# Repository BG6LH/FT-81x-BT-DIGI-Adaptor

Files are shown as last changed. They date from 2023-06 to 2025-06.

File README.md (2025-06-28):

views
views per week
clones
clones per week

Since 2025/06/11 



---
English | [简体中文](./README.zh-CN.md)

# A PCB Design of Bluetooth DIGI Adaptor for Yaesu FT-817/818 Series Transceivers

> **NOTE: This Design is still a Work in Progress. Schematic, PCB, and other stuff might change!**

## Table of Contents
- [Update](#update)
- [Important](#important)
- [Background](#background)
- [Design](#design)
- [Code Repositories](#code-repositories)
- [Configuration of JDY-67](#configuration-of-JDY-67)
- [3D Printed Protect Cover](#3d-printed-protect-cover)
- [Related Efforts](#related-efforts)
- [Contributing](#contributing)
- [Maintainers](#maintainers)
- [License](#license)

## Update

### Updated in 20240120

**Important:** Fixed the 20230609 version‘s power supply part's resistor value.

Right Choice should be this:
* R10 = 100KΩ
* R11 = 100KΩ
* R12 = 1KΩ
* R6 = 10Ω

The LM1117-3.3V is also a good choice.
All about that can work well at once!

The PCB design is as same as 20230609, so the old Gerber files are still work.

A 3D printed Cover has published:

[https://www.thingiverse.com/thing:6116435](https://www.thingiverse.com/thing:6116435)

### Updated in 20230609 

**Important:** The 20230608 version‘s symbols and footprints of Q1, Q2 are wrong. Please use updated in 20230609.

1. Update LDO LM1117-3.3V to 5V, to provide a constant power for the Bluetooth module;
2. Removed the Zener, and updated R6 to 150Ω, which is close to the ideal value;
3. Added power off circuit.
4. Replace VR with fixed resistor and optimize the circuit.
5. Updated some symbols and footprints.

### Updated in 20230527

The version 20230522‘s MD6 and MD8 sockets footprints were forgot to be grounded, if you has printed the PCB, you can scrape the green oil next to the shell's big pin, and then solder them together. It will as good as this version 20230527.

20230527's update includes:
1. Modified the symbols and footprints design of MD-6 and MD8 sockets, added pin 9, and grounded. Ensure that will not lost ground when updating from schematic.
2. The power divider resistor R6 is updated to 270Ω, which is close to the ideal value;
3. Added project's kicad symbols and footprints library sharing.

### Updated in 20230522
1. Add 6.2V zener for pre-conditioning before LM1117-3.3
2. Add attenuation network for Line->Mic
3. Add EMI inductor on TXD/RXD pins.
4. Removed TXD's LED.

## Important
1. The FT-817/818's ACC jack always has a constant voltage of 13.8V, even you switched off the rig. We should ***BE VERY CAREFUL*** to avoid short-circuit the PCB and ACC jack accidentally.
2. Meanwhile, aftering installing this adaptor, it will ***ALWAYS*** consume FT-817/818's battery energy. So, A battery with a power switch is recommended. For example, The WindCamp's FT-817/818 lithium battery.
3. If you would purchase a JDY-67 Bluetooth moudle, make sure the firmware version is ***Above 1.3***.

## Background
My friend BG6JJI designed a Bluetooth DIGI adaptor working for many old style TRXs with a Bluetooth, DIGI and CAT ability. He was using a Bluetooth module named JDY-67. I am not sure which manufacturer made the JDY-67. But it's really inexpensive and really works for Bluetooth Audio, and SPP in same time.

So, I pick up an old PCB design for my FT-818. It was design for FT8 cable connecting at very beginning. However, with JDY-67, It should works for Bluetooh/DIGI/CAT. I'd measured the DATA and ACC jacks on FT-818's rear panel, And refering to the FT-817ND's Service Manual, I think the Yaesu's PCB maybe design in a 0.635mm/0.025inch grid. Under this assumption, I'd drawn a PCB that could cover most of the FT-817 rear panel, and perfectly matched all the screw holes, jacks....precisely!!! It looks like a underwear(under-bottom-hardware), right?

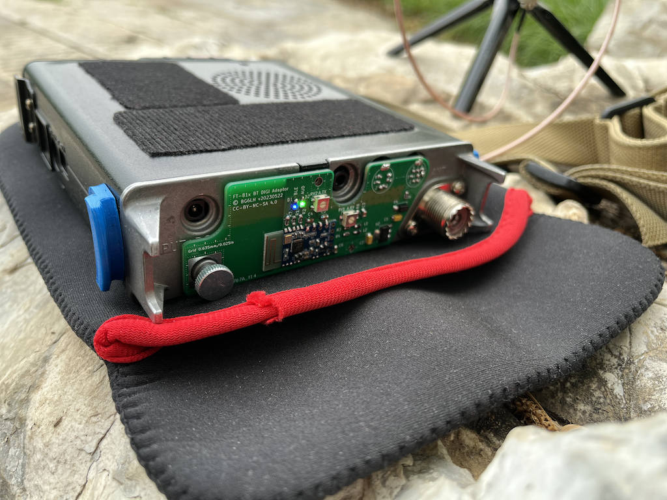
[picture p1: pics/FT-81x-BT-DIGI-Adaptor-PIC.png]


Although FT-817/818 has been discontinued, I still love this twenty years selling product. Now, I would like to share this PCB desgin to all HAM communities, If you wanna make your design, you can make any modify from it.

## Design
This PCB was design by KiCad 7.0
In the Layer User.Drawings and User.Comments, there are some information of measurement.
In the Layer User.1~4, there are approximate FT-817/818's panel sketch for comparison.

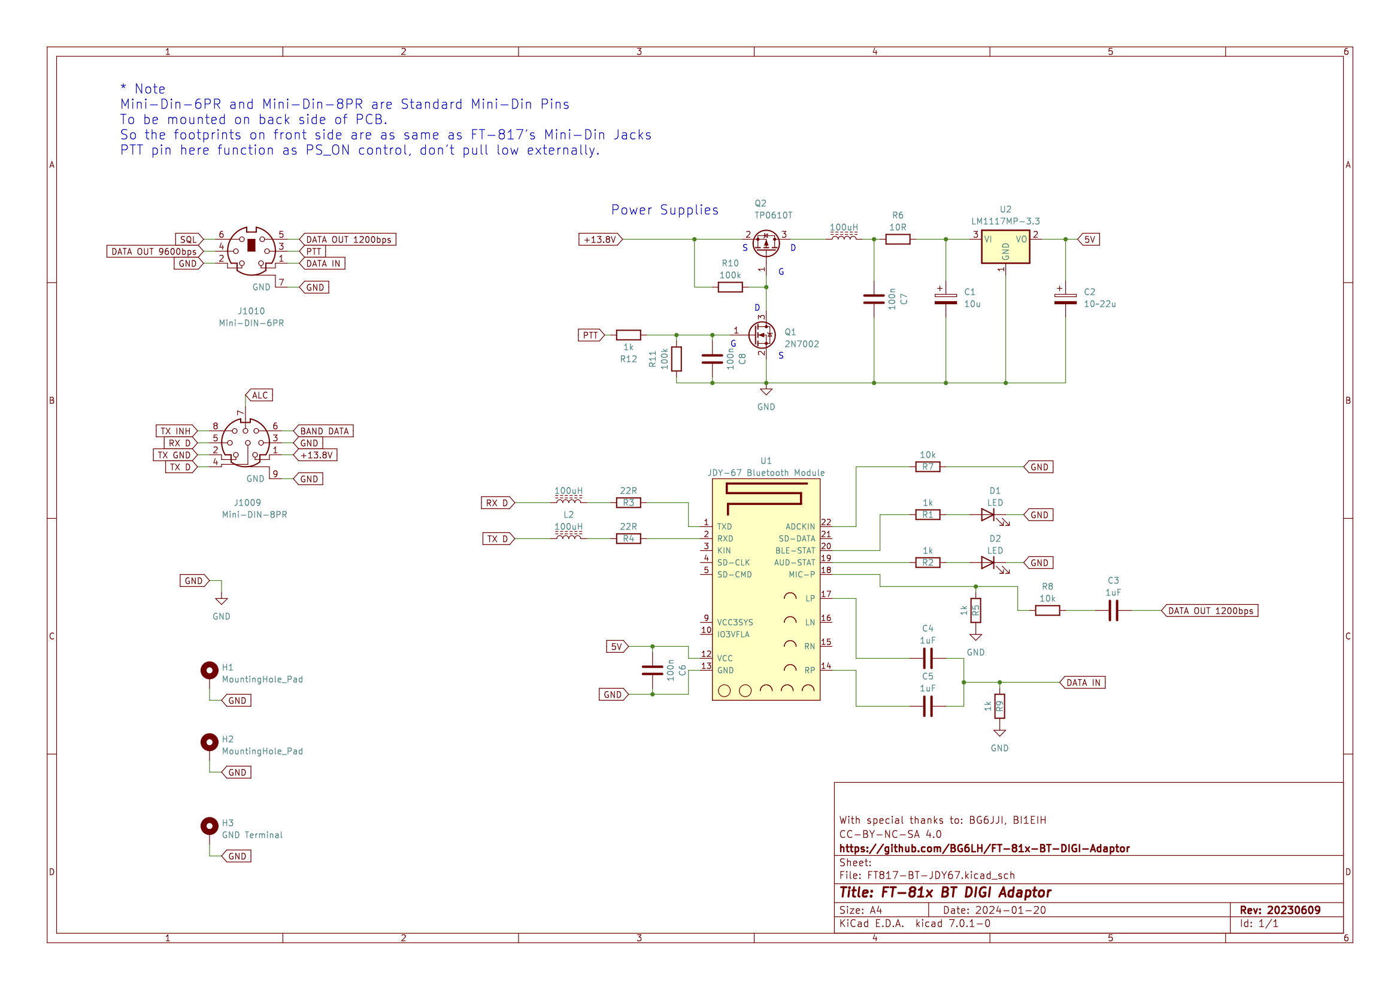
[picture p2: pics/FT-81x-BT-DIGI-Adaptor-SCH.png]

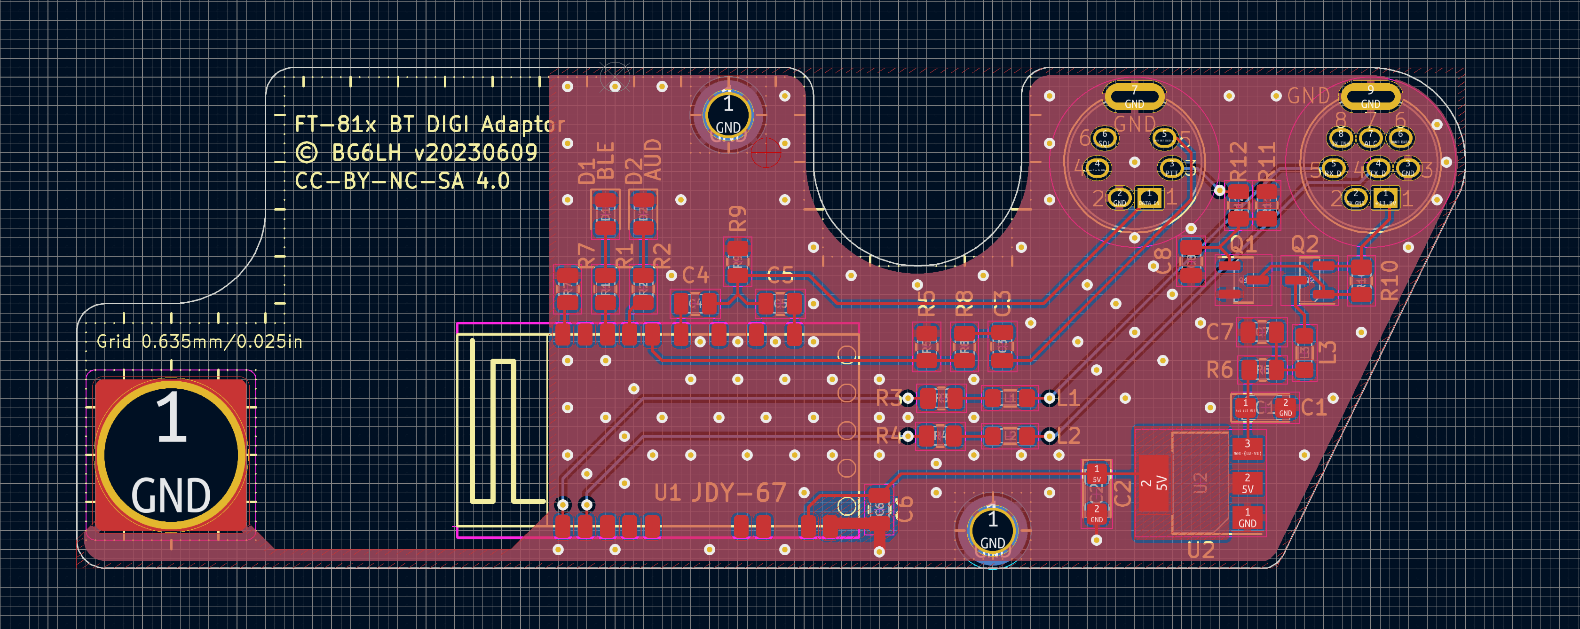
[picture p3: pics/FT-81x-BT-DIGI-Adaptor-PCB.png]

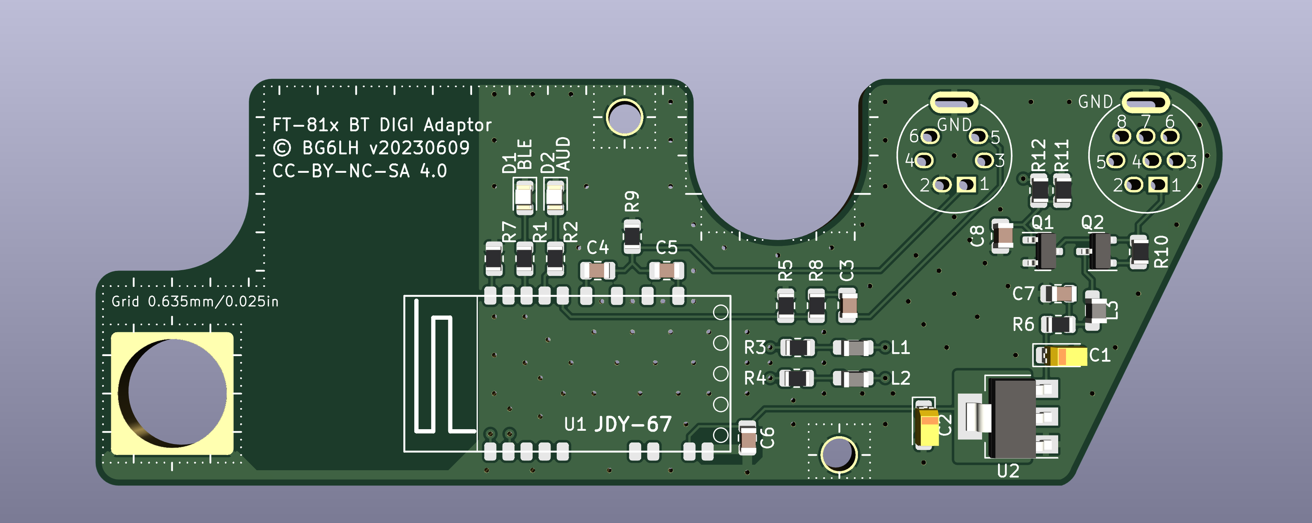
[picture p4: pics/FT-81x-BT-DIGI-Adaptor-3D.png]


## Code Repositories

- Github [https://github.com/BG6LH/FT-81x-BT-DIGI-Adaptor](https://github.com/BG6LH/FT-81x-BT-DIGI-Adaptor)
- Gitee [https://gitee.com/bg6lh/FT-81x-BT-DIGI-Adaptor](https://gitee.com/bg6lh/FT-81x-BT-DIGI-Adaptor)

## Configuration of JDY-67

Please note, the JDY-67's default BAUD is 9600bps.

Before connect the adaptor to phone or computer, there are three bluetooth configuration need to be changed. please use those serial port AT instructions:
```sh
AT+SING1\r\n
# Turn on single-ended output 

AT+ROLE0\r\n
# Turn off BLE bluetooth

AT+CALEN1\r\n
# Turn on the phone function

AT+RST\r\n
# Restart the moudule
```
Jdy-67 module serial command must be plus \r\n .

## 3D Printed Protect Cover

A 3D printed Cover has published:
[https://www.thingiverse.com/thing:6116435](https://www.thingiverse.com/thing:6116435)

## Related Efforts
- [FT8CN for Android](https://github.com/N0BOY/FT8CN) - Run FT8 natively on Android. This app works well with our Bluetooth DIGI Adaptor.

## Contributing
With special thanks to **BG6JJI, BI1EIH***. They give me many generous advice.

Let's enjoy the FT-817's last lucky underware together!!

## Maintainers
- [@BG6LH(me)](https://github.com/BG6LH)
- [@sgub(BI1EIH)](https://github.com/sgub)

## Star History

Star History Chart (https://www.star-history.com/#BG6LH/FT-81x-BT-DIGI-Adaptor&Date)

## License

This work is licensed under a
[Creative Commons Attribution-NonCommercial-ShareAlike 4.0 International (CC BY-NC-SA 4.0)][cc-by-nc-sa].

[][cc-by-nc-sa]

[cc-by-nc-sa]: https://creativecommons.org/licenses/by-nc-sa/4.0/
[cc-by-nc-sa-image]: https://i.creativecommons.org/l/by-nc-sa/4.0/88x31.png

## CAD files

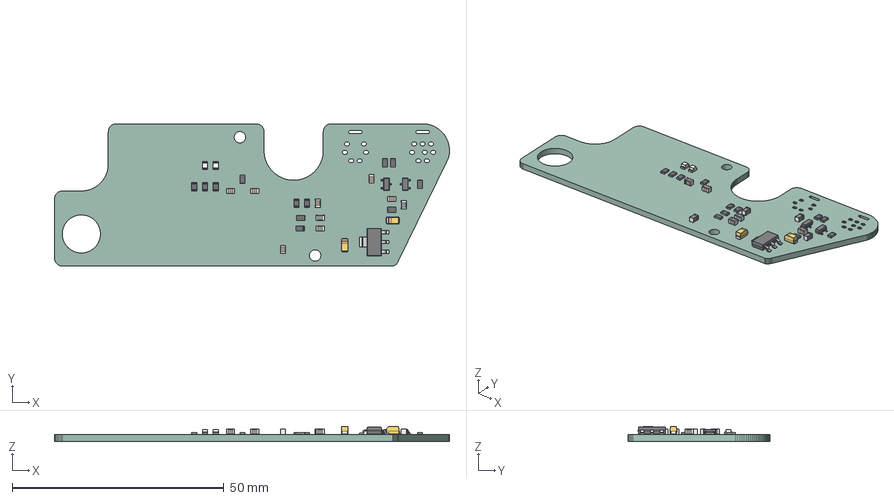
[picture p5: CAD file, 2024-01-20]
FT817-BT-JDY67.step
93.3 x 33.7 x 3.43 mm
PCB

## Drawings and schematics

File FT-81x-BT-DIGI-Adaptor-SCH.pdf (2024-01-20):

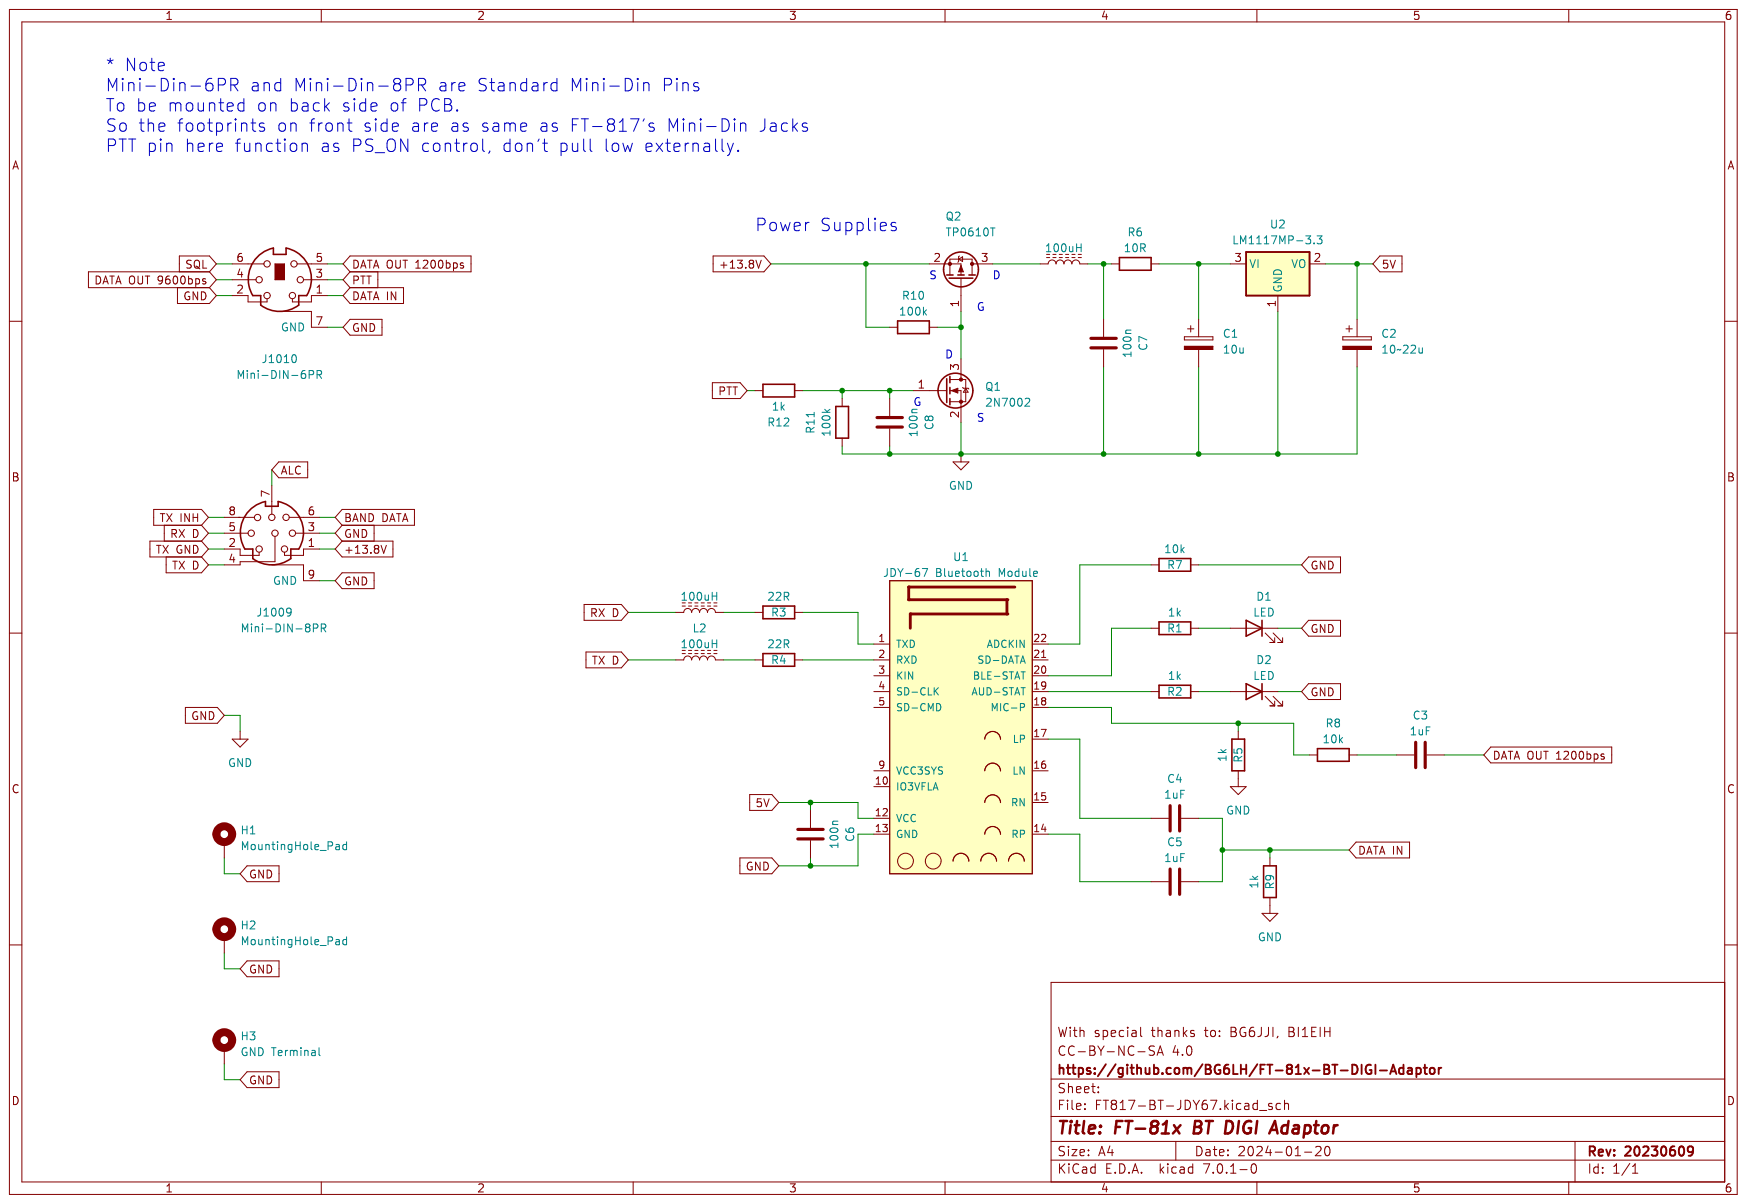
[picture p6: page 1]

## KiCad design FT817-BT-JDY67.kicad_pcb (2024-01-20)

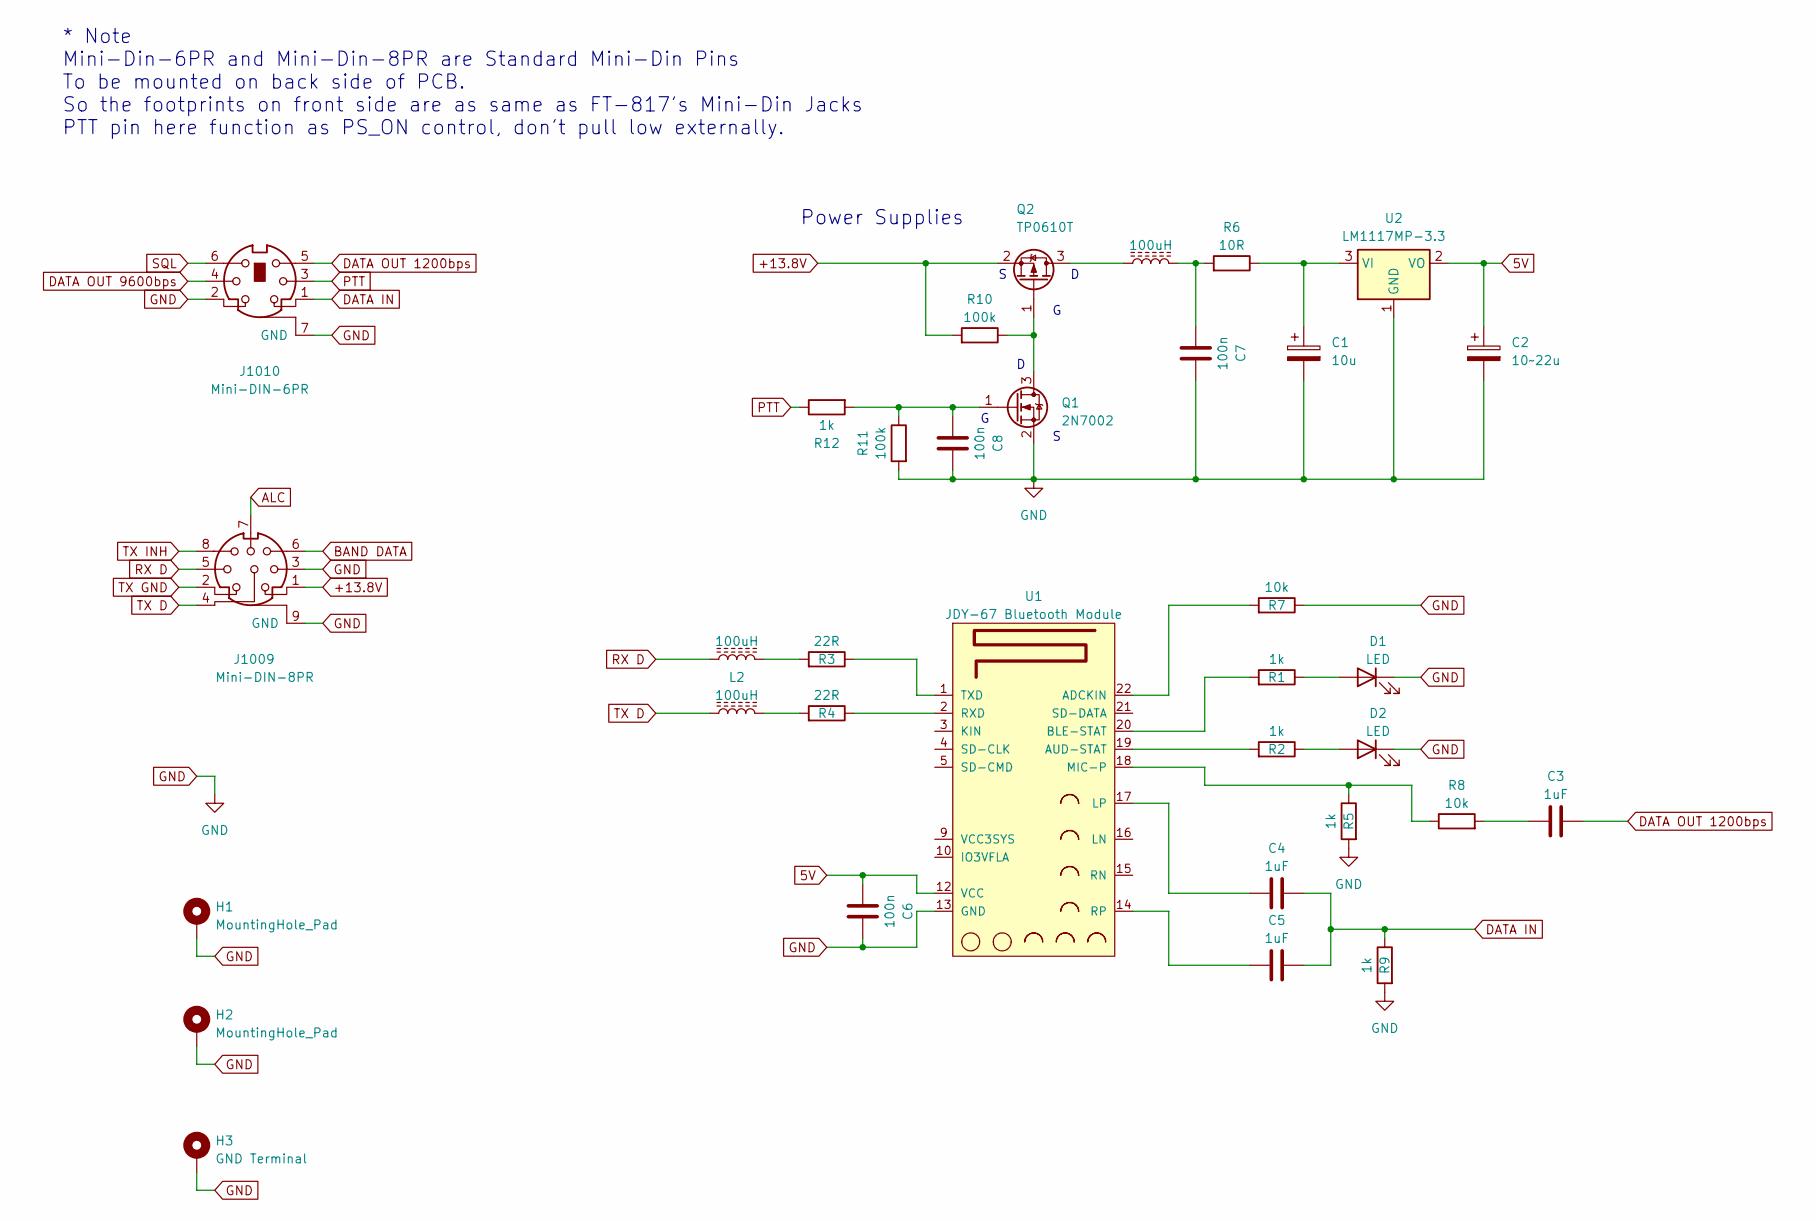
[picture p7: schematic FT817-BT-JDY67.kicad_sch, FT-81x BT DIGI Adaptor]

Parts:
C1: 10u; CP_EIA-3216-18_Kemet-A
C2: 10~22u; CP_EIA-3216-18_Kemet-A
C3, C4, C5: 1uF; C_0805_2012Metric
C6, C7, C8: 100n; C_0805_2012Metric
D1, D2: LED; LED_0805_2012Metric
H1, H2: MountingHole_Pad; MountingHole_2.7mm_M2.5_DIN965_Pad_TopOnly
H3: GND Terminal; FT-817_GND_terminal_8.4mm_M8_Pad_TopBottom
J1009: Mini-DIN-8PR; MD-8Pin_Reverse
J1010: Mini-DIN-6PR; MD-6Pin_Reverse
L1, L2, L3: 100uH; L_0805_2012Metric_Pad1.05x1.20mm_HandSolder
Q1: 2N7002; SOT-23
Q2: TP0610T; SOT-23
R1, R2, R5, R9, R12: 1k; R_0805_2012Metric
R3, R4: 22R; R_0805_2012Metric
R6: 10R; R_0805_2012Metric
R7, R8: 10k; R_0805_2012Metric
R10, R11: 100k; R_0805_2012Metric
U1: JDY-67 Bluetooth Module; JDY-67_Bluetooth_Module
U2: LM1117MP-3.3; SOT-223-3_TabPin2

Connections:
5V: C2.1, C6.1, U1.12 (VCC), U2.2 (VO)
+13.8V: J1009.1, Q2.2 (S), R10.2
ALC: J1009.7
BAND DATA: J1009.6
DATA IN: C4.2, C5.2, J1010.1, R9.1
DATA OUT 1200bps: C3.2, J1010.5
DATA OUT 9600bps: J1010.4
GND: C1.2, C2.2, C6.2, C7.2, C8.2, D1.1 (K), D2.1 (K), H1.1, H2.1, H3.1, J1009.3, J1009.9 (GND), J1010.2, J1010.7 (GND), Q1.2 (S), R5.2, R7.1, R9.2, R11.2, U1.13 (GND), U2.1 (GND)
unnamed: C3.1, R8.2
unnamed: C7.1, L3.2, R6.2
unnamed: D1.2 (A), R1.1
unnamed: D2.2 (A), R2.1
unnamed: L1.2, R3.2
unnamed: L2.2, R4.2
unnamed: Q1.3 (D), Q2.1 (G), R10.1
unnamed: C8.1, Q1.1 (G), R11.1, R12.2
unnamed: L3.1, Q2.3 (D)
unnamed: R7.2, U1.22 (ADCKIN)
unnamed: R2.2, U1.19 (AUD-STAT)
unnamed: R1.2, U1.20 (BLE-STAT)
unnamed: C4.1, U1.17 (LP)
unnamed: R5.1, R8.1, U1.18 (MIC-P)
unnamed: C5.1, U1.14 (RP)
unnamed: R4.1, U1.2 (RXD)
unnamed: R3.1, U1.1 (TXD)
unnamed: C1.1, R6.1, U2.3 (VI)
PTT: J1010.3, R12.1
RX D: J1009.5, L1.1
SQL: J1010.6
TX D: J1009.4, L2.1
TX GND: J1009.2
TX INH: J1009.8

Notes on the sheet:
* Note Mini-Din-6PR and Mini-Din-8PR are Standard Mini-Din Pins To be mounted on back side of PCB. So the footprints on front side are as same as FT-817's Mini-Din Jacks PTT pin here function as PS_ON control, don't pull low externally.
Power Supplies

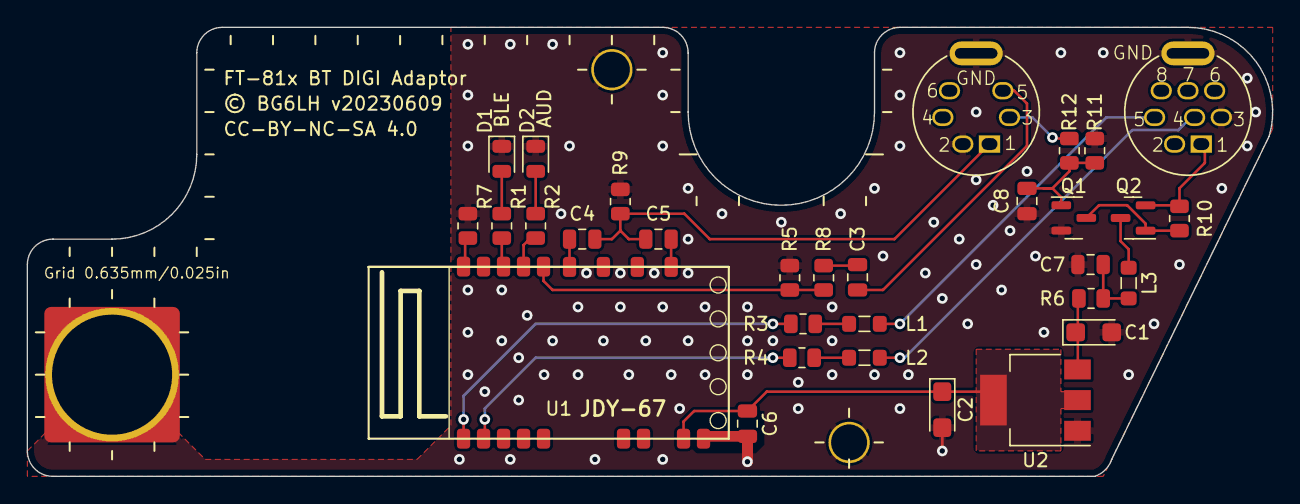
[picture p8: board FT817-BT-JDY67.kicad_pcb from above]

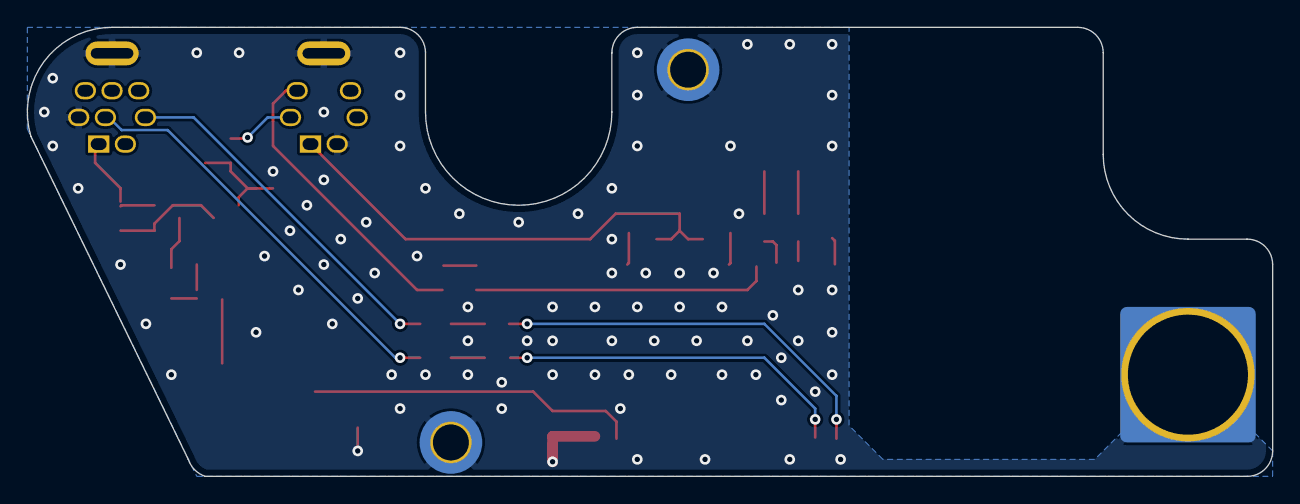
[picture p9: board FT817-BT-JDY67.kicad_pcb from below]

Board: 2 copper layers, 93.3 x 33.7 mm, 34 parts (2 on the bottom side), 26 nets.

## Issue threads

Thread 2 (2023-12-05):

source for mini DIN connector

cogwheelcircuitworks, 2023-12-05:
Can someone provide source for the mini DIN connectors..

Also, is there a chat group where people are sharing experience building this? Tnx.

erkanz, 2024-01-17:
Hello , Do you have the part number for the connectors? Where can I order it from? Thank you.

BG6LH, 2024-01-20:
no part number could be found. it should be solved by yourself.

Closed 2024-01-20.

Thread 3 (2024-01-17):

New Resistor Choice

BG6LH, 2024-01-17:
The BOM list of 0609 has some mistakes.

Right Choice should be this:
* R10 = 100KΩ
* R11 = 100KΩ
* R12 = 1KΩ
* R6 = 10Ω

The LM1117-3.3V is also a good choice.
All about that can work well at once!

BG6LH, 2024-01-20:
updated the mistakes and republican new version.

Closed 2024-01-20.

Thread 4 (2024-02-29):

Sending AT commands

CT7ABA, 2024-02-29:
Hello, I need your help for configuring the module.
I'm trying to connect to the module with an usb to serial adapter and a terminal program but it does not work.
Is there a pin to enable the module to receive AT commands?

mni tnx es 73 de Frederico

BG6LH, 2024-03-19:
have you tried AT commands with or without the "\r\n"?

CT7ABA, 2024-03-28:
It does not work with and without, it looks like I got some fake modules.
I have create my own PCB with the BT-401 Module and it works fine
73 Frederico.

CT7ABA, 2024-03-28:
thanks

BG6LH, 2024-04-02:
BT401 is my next target.

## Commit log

2023-05-17 add a 3D mod of JDY-67
    adjust the dimension
    [FT817-BT-JDY67.kicad_pcb]
2023-05-21 1. Add 6.2V zener for pre-conditioning before LM1117-3.3 2. Add attenuation network for Line->Mic 3. Add EMI inductor on TXD/RXD pins.
    [FT817-BT-JDY67.kicad_sch]
2023-05-22 Reconnect D3 to RXD
    [FT817-BT-JDY67.kicad_sch]
2023-05-22 Updated footprint for new components.
    [FT817-BT-JDY67.kicad_sch]
2023-05-24 minimal update
    [FT817-BT-JDY67.kicad_pcb, FT817-BT-JDY67.kicad_sch]
2023-05-24 增加中文版说明
2023-06-05 Replace VR with fixed resistor. Optimized LDO circuit.
    [FT817-BT-JDY67.kicad_sch]
2023-06-07 Add power shutdown circuit
    [FT817-BT-JDY67.kicad_sch]
2023-06-07 Remove VCC control bypass jumper
    [FT817-BT-JDY67.kicad_sch]
2023-06-09 Error founded
    [FT817-BT-JDY67-B_Cu.gbr, FT817-BT-JDY67-B_Mask.gbr, FT817-BT-JDY67-B_Paste.gbr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]
2023-06-09 Important update
    [FT817-BT-JDY67-B_Cu.gbr, FT817-BT-JDY67-B_Mask.gbr, FT817-BT-JDY67-B_Paste.gbr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]
2024-01-20 resistors value update
    updated power supply's resistor right value.
    [FT817-BT-JDY67-B_Cu.gbr, FT817-BT-JDY67-B_Mask.gbr, FT817-BT-JDY67-B_Paste.gbr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]

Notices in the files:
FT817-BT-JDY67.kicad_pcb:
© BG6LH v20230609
